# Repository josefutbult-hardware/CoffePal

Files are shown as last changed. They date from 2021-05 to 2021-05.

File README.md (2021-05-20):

# CoffeePal

_Upbeat music starts_.

Have YOU ever forgotten a cup of coffee for too long when working on a project, resulting in a cold cup of liquid sadness? Then the _Coffee Pal_ is for YOU!

Jokes aside, even though I'm one of those sadistic people who enjoy cold coffee, this actually is a bit of a problem for me. It is an even bigger problem for my mum, who regulary walks away from her cups. The idea with the Coffee Pal is to have a little gadget that you can clip onto a cup. This will then sense when a cup has been stationary for too long, and then starts to make a noise to remind you to drink from it. This will continue periodically until the cup has been moved, and hopefully has been drunk from. There is also a light sensor on there that will disable the notification if the room is too dark, to make sure it won't wake you up in the middle of the night if you've forgotten it. Everything is on a small PCB that runs on a coin cell battery, and with a plastic clamp to fasten it to the cup.

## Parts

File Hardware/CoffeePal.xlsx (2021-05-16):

Qty | MPN | Mouser PN | Value | Device | Package | Parts | Description | LINK | POPULARITY | SUPPLIER | TP_SIGNAL_NAME
3 | C0603C104K5RAC3121 | 80-C603C104K5RAC3121 | 100n | CAPACITORC-0603 | 603 | C1, C2, C3 | Capacitor
1 | 1061TR | 534-1061TR | 1061TR | 1061TR | 1061TR | U$2 | Battery clip | https://eu.mouser.com/ProductDetail/Keystone-Electronics/1061TR?qs=q0tsjPZWdm8mEkIEudXsxA%3D%3D |  | Mouser
5 | RC0603FR-071KL | 603-RC0603FR-071KL | 1k | RESISTOR | R0603 | R1, R5, R7, R8, R9
1 | 5-146258-3 | 571-5-146258-3 | 3X2_PINHEADER3X2_PINHEADER | 3X2_PINHEADER3X2_PINHEADER | HDRV6W64P254_2X3_900X508X838B | PROGRAM |  | https://eu.mouser.com/ProductDetail/TE-Connectivity/5-146258-3?qs=lf8um9gOXCICbEgdwHMcdQ%3D%3D |  | Mouser
4 | AC0603JR-134K7L | 603-AC0603JR-134K7L | 4.7k | RESISTOR | R0603 | R2, R3, R4, R6
1 | ATTINY85V-10SUR | 556-ATTINY85V-10SUR | ATTINY85SOIC-8 | ATTINY85SOIC-8 | SOIC127P798X216-8N | U1 | ATTiny 85 | https://www.mouser.se/ProductDetail/Microchip-Technology-Atmel/ATTINY85V-10SUR?qs=6Dg1WZIWLC7RsRgydzBFFw%3D%3D |  | Mouser
1 | BH1745NUC-E2 | 755-BH1745NUC-E2 | BH1745NUC-E2WSON008X2120 | BH1745NUC-E2WSON008X2120 | SON50P210X200X60-9T75X150N | U2 | Photosensor | https://eu.mouser.com/ProductDetail/ROHM-Semiconductor/BH1745NUC-E2 |  | Mouser
1 | CMPT3904E TR PBFREE | 610-CMPT3904E | CMPT3904ETRPBFREESOT23 | CMPT3904ETRPBFREESOT23 | SOT95P240X110-3N | U4 | NPN Transistor | https://eu.mouser.com/ProductDetail/Central-Semiconductor/CMPT3904E-TR-PBFREE?qs=u16ybLDytRZdO89O3AipsA%3D%3D |  | Mouser
1 | 621-1N4448W-F | 1N4448W-7-F | 1N4448W-7-F | 1N4448W-7-F | SOD-123_MINI-SMA | D1 | Molded plasitc,JEDEC SOD-123/Mini SMA | https://www.mouser.se/ProductDetail/Diodes-Incorporated/1N4448W-7-F?qs=VlTXaPCrgsfMz34DB76PhQ%3D%3D | 0
1 | 604-APTR3216QBC/D | APTR3216QBC/D | LEDLED_1206 | LEDLED_1206 | DIOC3216X75N | LED1
1 | MC3413 | 498-MC3413 | MC3413 | MC3413 | VLGA-12 | U5 | Accelerometer | https://eu.mouser.com/ProductDetail/MEMSIC/MC3413?qs=8TPl4Kup7ocS%2FG2RQqpI2Q%3D%3D |  | Mouser
1 | MFS201N−9−Z | 229-MFS201N-9-Z | MFS201N−9−Z | MFS201N−9−Z | MFS201N-9-Z | S1 | Switch | https://eu.mouser.com/ProductDetail/Nidec-Copal/MFS201N-9-Z?qs=XeJtXLiO41Ra%252BPt0rLIsIw%3D%3D |  | Mouser
1 | TP143305-1 | 497-TP143305-1 | TP143305-1PIETZO | TP143305-1PIETZO | SODFL151143X1070N | U3 | Pietzo | https://eu.mouser.com/ProductDetail/DB-Unlimited/TP143305-1?qs=t9M3m0YJX4N5fN9KSkHojQ%3D%3D |  | Mouser

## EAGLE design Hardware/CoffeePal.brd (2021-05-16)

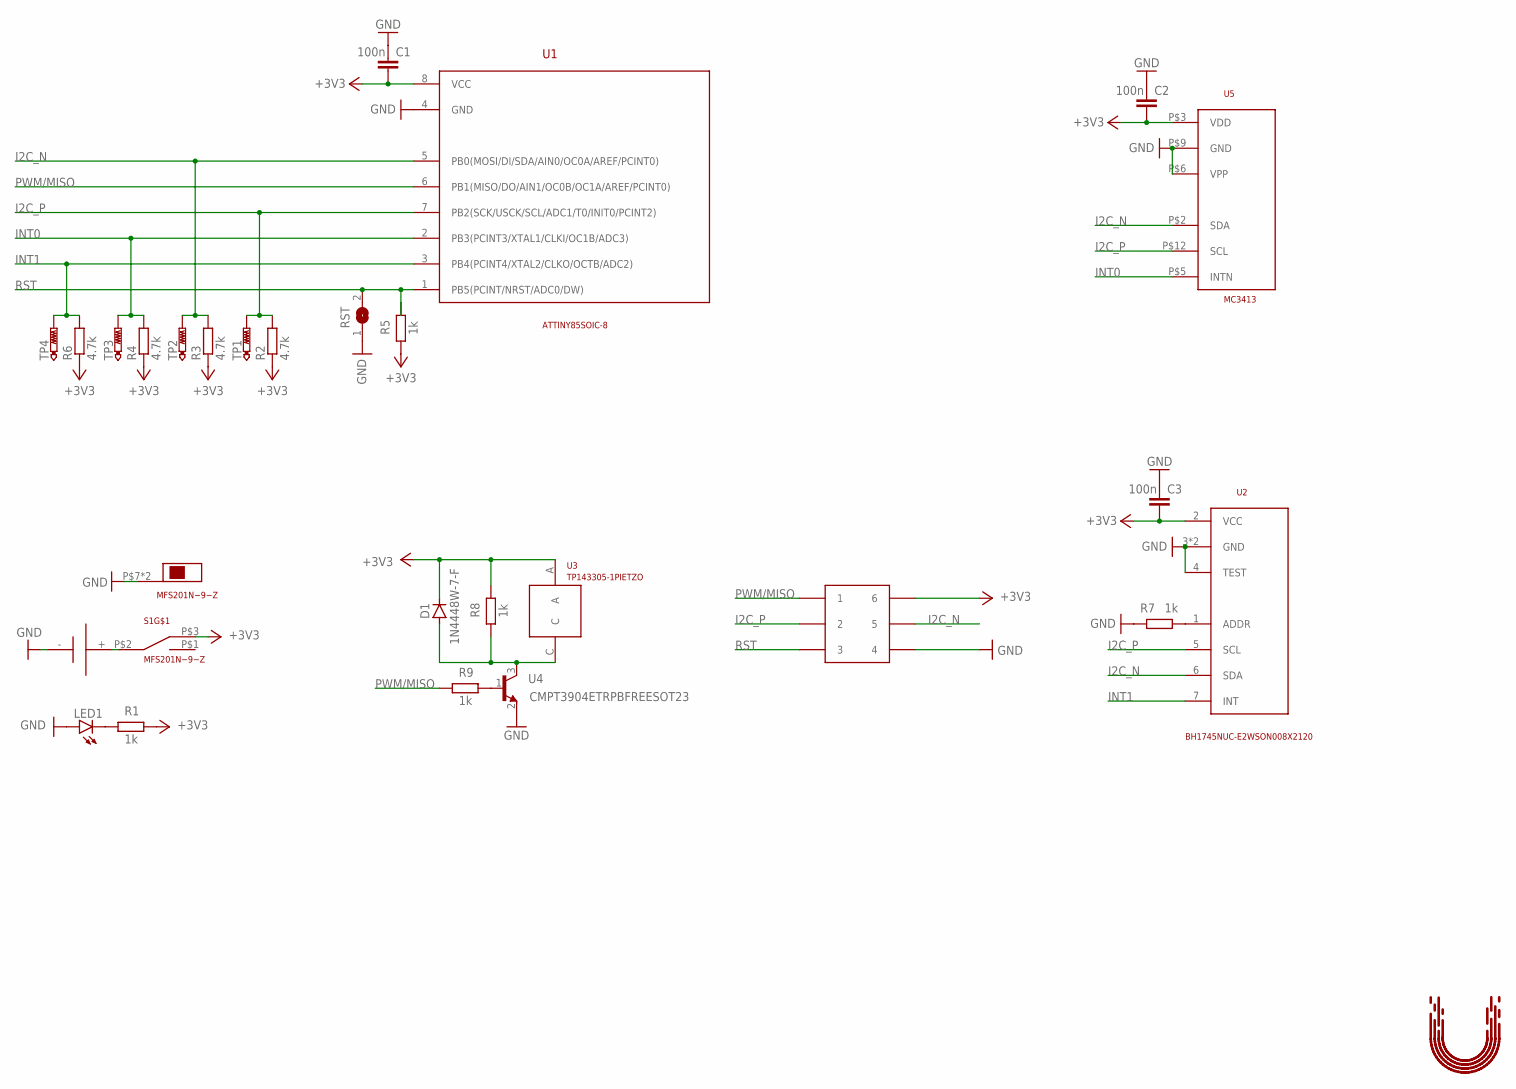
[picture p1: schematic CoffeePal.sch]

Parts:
C1, C2, C3: 100n; 0603
D1: 1N4448W-7-F; SOD-123_MINI-SMA; MPN 1N4448W-7-F
LED1: LEDLED_1206; DIOC3216X75N
PROGRAM: 3X2_PINHEADER3X2_PINHEADER; HDRV6W64P254_2X3_900X508X838B
R1, R5, R7, R8, R9: 1k; R0603
R2, R3, R4, R6: 4.7k; R0603
RST: JUMPER; SJ
S1: MFS201N−9−Z; MFS201N-9-Z
TP1, TP2, TP3, TP4: PTR1B1,27; B1,27
U1: ATTINY85SOIC-8; SOIC127P798X216-8N
U2: BH1745NUC-E2WSON008X2120; SON50P210X200X60-9T75X150N
U3: TP143305-1PIETZO; SODFL151143X1070N
U4: CMPT3904ETRPBFREESOT23; SOT95P240X110-3N
U5: MC3413; VLGA-12
U$2: 1061TR
U$3: UTBULT_DESIGN1; UD_1

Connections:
+3V3: C1.2, C2.2, C3.2, D1.C, PROGRAM.6, R1.2, R2.1, R3.1, R4.1, R5.1, R6.1, R8.2, S1.P$3, U1.8 (VCC), U2.2 (VCC), U3.A, U5.P$3 (VDD)
GND: C1.1, C2.1, C3.1, LED1.A, PROGRAM.4, R7.1, RST.1, S1.P$7, S1.P$8, U1.4 (GND), U2.3 (GND), U2.4 (TEST), U2.9 (GND), U4.2 (E), U5.P$6 (VPP), U5.P$9 (GND), U$2.-
I2C_N: PROGRAM.5, R3.2, TP2.TP, U1.5 (PB0(MOSI/DI/SDA/AIN0/OC0A/AREF/PCINT0)), U2.6 (SDA), U5.P$2 (SDA)
I2C_P: PROGRAM.2, R2.2, TP1.TP, U1.7 (PB2(SCK/USCK/SCL/ADC1/T0/INIT0/PCINT2)), U2.5 (SCL), U5.P$12 (SCL)
INT0: R4.2, TP3.TP, U1.2 (PB3(PCINT3/XTAL1/CLKI/OC1B/ADC3)), U5.P$5 (INTN)
INT1: R6.2, TP4.TP, U1.3 (PB4(PCINT4/XTAL2/CLKO/OCTB/ADC2)), U2.7 (INT)
unnamed: S1.P$2, U$2.+
unnamed: LED1.C, R1.1
unnamed: R7.2, U2.1 (ADDR)
unnamed: R9.2, U4.1 (B)
unnamed: D1.A, R8.1, U3.C, U4.3 (C)
PWM/MISO: PROGRAM.1, R9.1, U1.6 (PB1(MISO/DO/AIN1/OC0B/OC1A/AREF/PCINT0))
RST: PROGRAM.3, R5.2, RST.2, U1.1 (PB5(PCINT/NRST/ADC0/DW))

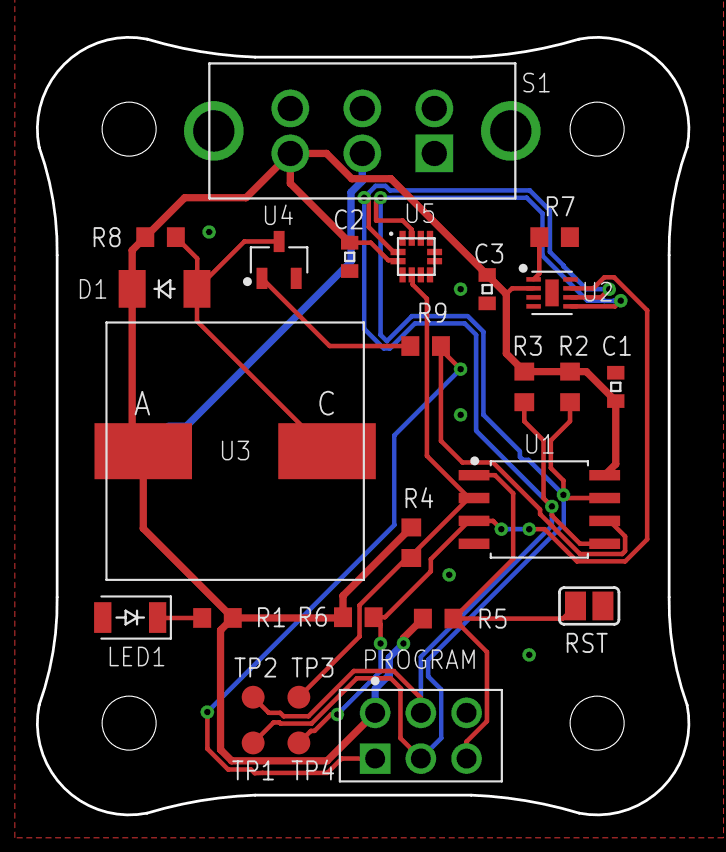
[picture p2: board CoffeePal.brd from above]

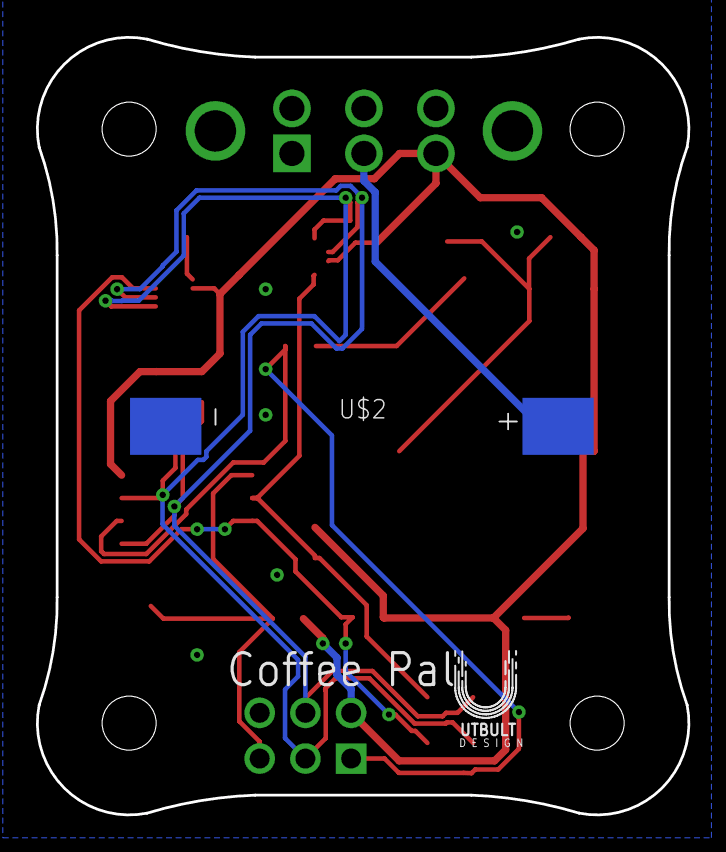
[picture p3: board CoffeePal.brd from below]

Board: 2 copper layers, 36.2 x 43.2 mm, 28 parts (2 on the bottom side), 13 nets.
